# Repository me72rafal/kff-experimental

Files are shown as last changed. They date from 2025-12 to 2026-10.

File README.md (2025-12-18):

# Kung Fu Flash

Cartridge for the Commodore 64 that packs a punch.

Kung Fu Flash Launcher

Kung Fu Flash can emulate different cartridge types, load PRG files and use D64 disk images.
Just place your desired CRT, PRG or D64 files on a FAT formatted microSD card and use the built-in launcher to execute them.

## Hardware

There are three buttons on the cartridge; a reset button, a menu button for starting the launcher, and a special button that is used by the freezer cartridges.

Cartridge Case

The PCB will fit the Stumpy Cartridge Case from TFW8b, you just need to drill some holes for the buttons and make a cut for the microSD card.
If you have mounted the USB connector you will need to cut a hole for that as well.

You can also 3D print a cartridge case as the one designed by bigby, [see here](https://www.thingiverse.com/thing:4153414).

Kung Fu Flash PCB

The gerber files and BOM can be found [here](https://codeberg.org/KimJorgensen/KungFuFlash/releases/tag/rev.2).

## Supported Cartridges

The following cartridge types are currently supported:

* Generic cartridge (8k, 16k, Ultimax)
* Action Replay v4.x/v5/v6
* KCS Power Cartridge
* Final Cartridge III(+)
* Simons' BASIC
* Fun Play, Power Play
* Super Games
* Ocean type 1
* Epyx Fastload
* C64 Game System, System 3
* WarpSpeed
* Dinamic
* Zaxxon, Super Zaxxon
* Magic Desk, Domark, HES Australia
* Super Snapshot v5
* Comal-80
* Ross
* EasyFlash
* Prophet64
* Freeze Frame
* Freeze Machine
* MACH 5
* Pagefox
* RGCD, Hucky
* Drean
* C128 Generic cartridge (external function ROM)
* WarpSpeed 128

## Supported File Types

The following file types are currently supported:

* Cartridge (CRT)
* C64/C128 generic cartridge (ROM, BIN)
* Disk image (D64, D71, D81)
* Tape image (T64)
* Program (PRG, P00)
* Firmware update (UPD)
* Text document (TXT, NFO, 1ST)

## USB Port

The USB port allows programs or disk images to be transferred from/to a PC using the EasyFlash 3 USB protocol.
The USB port is active when:

* The Kung Fu Flash launcher is running
* A program is started using "Load" in the file options menu (SHIFT+RETURN)
* BASIC is started via F7 in the launcher

Kung Fu Flash shows up as a standard serial port when connected to a PC not requiring any custom drivers to be installed.
This means, however, that the EasyFlash 3 program on the PC side must be modified to support Kung Fu Flash.
For that reason a modified version of [EasyFlash 3 USB Utilities](3rd_party/ef3utils) and [EasyFlash 3 BBS](3rd_party/ef3bbs) has been included in this repository.

## Firmware Update

Just place the KungFuFlash_v1.xx.upd file on the SD card and select the file in the launcher to initiate the firmware update.
The newest firmware can be found [here](https://codeberg.org/KimJorgensen/KungFuFlash/releases/).

For initial firmware installation, [see here](firmware/README.md).

## Limitations

Kung Fu Flash is a so called Software Defined Cartridge where a fast microcontroller emulates cartridge hardware in software.
This makes it extremely flexible, allowing different cartridge types to be supported at a relative low cost.

However, it can be challenging to get the C64 bus timing correct in software and in some places the timing is very close to the limit.
Even though Kung Fu Flash has been tested on different models of the Commodore 64, there is a chance that it doesn't work correctly on your specific model, or requires [phi2 offset adjustment](firmware/README.md#diagnostic).
Use it at your own risk!

Kung Fu Flash will work with the PAL and NTSC version of the Commodore 64 or Commodore 128.

Disk drive emulation is using kernal vectors and will not work with fast loaders or software that uses direct hardware access which a lot of games does.
Currently REL files are not supported and only a subset of the Commodore DOS commands are supported.

## Thanks

Kung Fu Flash was based on or uses other open source projects:

* [EasyFlash 3](https://bitbucket.org/skoe/easyflash) by Thomas Giesel
* [Draco Browser](https://csdb.dk/release/?id=89910) by Sascha Bader
* [fatfs-stm32](https://github.com/colosimo/fatfs-stm32) by Aurelio Colosimo
* [FatFs](http://elm-chan.org/fsw/ff/00index_e.html) by ChaN
* [libusb_stm32](https://github.com/dmitrystu/libusb_stm32) by Dmitry Filimonchuk
* [stm32f4-bare-metal](https://github.com/fcayci/stm32f4-bare-metal) by Furkan Cayci
* [OpenC64Cart](https://github.com/SukkoPera/OpenC64Cart) by Giorgioggì
* [EasyFlash 3 USB Utilities](https://csdb.dk/release/?id=150097) by Tomaz Kac
* [Disk2easyflash](https://csdb.dk/release/?id=150323) by ALeX Kazik

and a few others. Please check the individual files for their license.

Thanks to Bjørn N. Jørgensen for giving this project its name.

Special thanks to the author of [Sidekick64](https://github.com/frntc/Sidekick64) Carsten Dachsbacher for his support and inspiration.

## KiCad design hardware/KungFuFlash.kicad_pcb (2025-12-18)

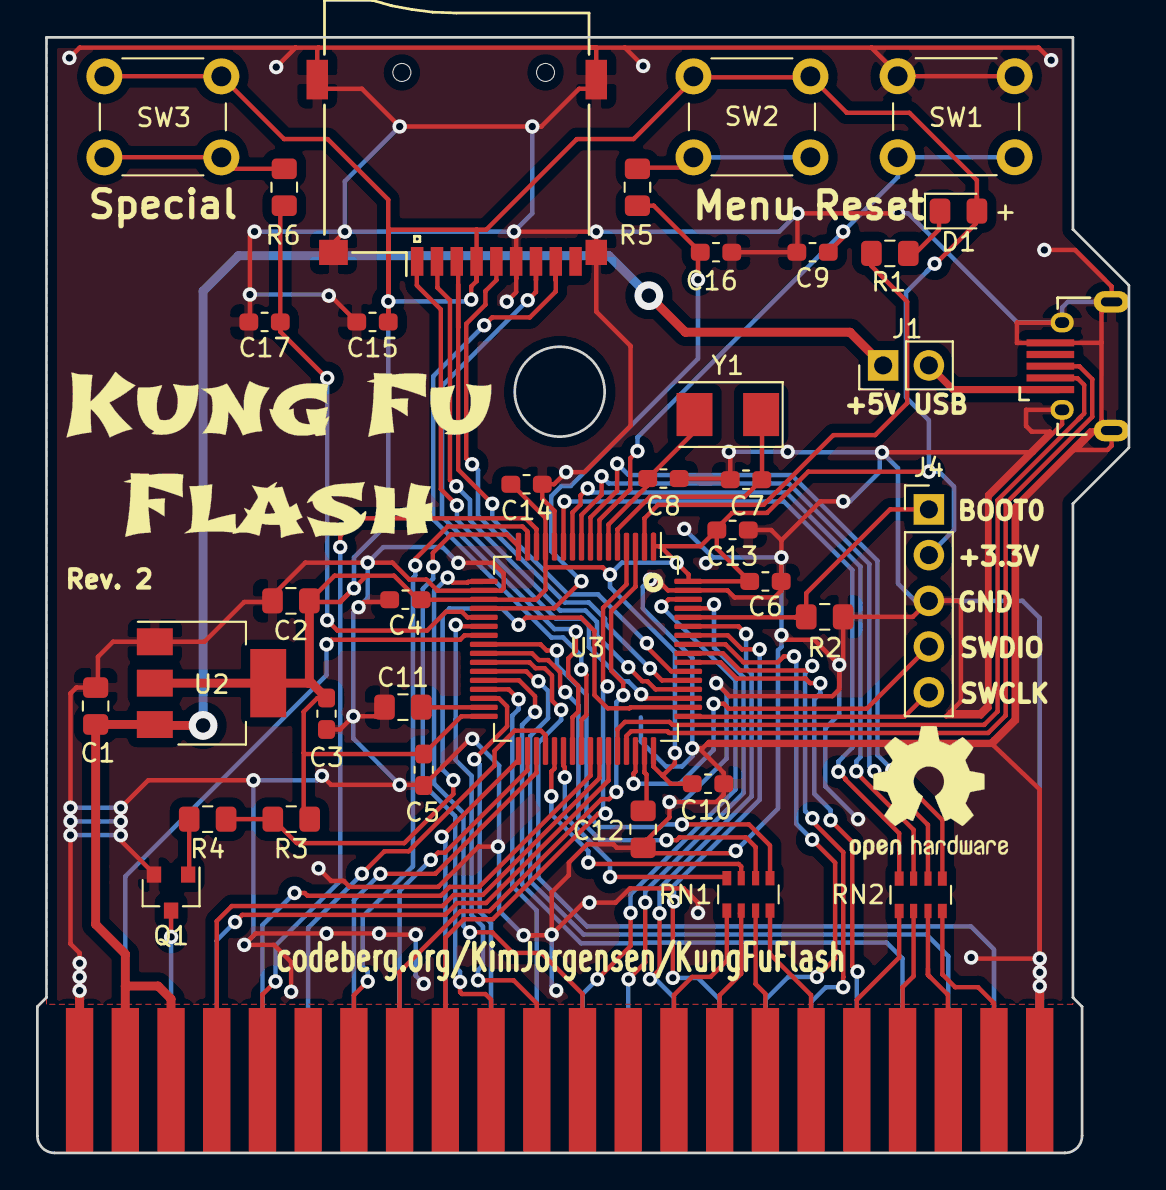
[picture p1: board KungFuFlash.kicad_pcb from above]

Board: 2 copper layers, 60.6 x 62.0 mm, 38 parts (0 on the bottom side), 72 nets.

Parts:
C1, C2: 10u; C_0805_2012Metric_Pad1.15x1.40mm_HandSolder
C3, C4, C5, C6, C9, C10, C13, C14, C15, C16, C17: 100n; C_0603_1608Metric_Pad1.05x0.95mm_HandSolder
C7, C8: 20p; C_0603_1608Metric_Pad1.05x0.95mm_HandSolder
C11, C12: 2.2u; C_0805_2012Metric_Pad1.15x1.40mm_HandSolder
D1: LED; LED_0805_2012Metric_Pad1.15x1.40mm_HandSolder
J1: USB Power; PinHeader_1x02_P2.54mm_Vertical
J2: USB_B_Micro; Conn_USBmicro-B_ebay-side_TH
J4: SWD; PinHeader_1x05_P2.54mm_Vertical
Q1: BC817; SOT-23
R1, R4, R5, R6: 510R; R_0805_2012Metric_Pad1.15x1.40mm_HandSolder
R2, R3: 10k; R_0805_2012Metric_Pad1.15x1.40mm_HandSolder
RN1, RN2: 100R; R_Array_Convex_4x0603
SW1: Reset; SW_PUSH_6mm_H8mm
SW2: Menu; SW_PUSH_6mm_H8mm
SW3: Special; SW_PUSH_6mm_H8mm
U1: C64-Exp-Port; C64-Cart
U2: AMS1117-3.3; SOT-223-3_TabPin2
U3: STM32F405RGTx; LQFP-64_10x10mm_P0.5mm
XS1: uSD_push_push; Conn_uSDcard
Y1: 8MHz; Crystal_SMD_5032-2Pin_5.0x3.2mm

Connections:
+3V3: C2.1, C3.1, C4.1, C5.1, C6.1, C10.1, C13.1, C14.1, C15.1, D1.2, J4.2, R3.1, SW2.1, SW3.1, U2.2, U3.1, U3.13, U3.19, U3.32, U3.48, U3.64, XS1.4
+5C: J1.2, J2.1
+5V: C1.1, J1.1, U1.2, U1.3, U2.3
/A0: U1.Y, U3.26
/A1: U1.X, U3.27
/A2: U1.W, U3.28
/A3: U1.V, U3.55
/A4: U1.U, U3.56
/A5: U1.T, U3.57
/A6: U1.S, U3.58
/A7: U1.R, U3.59
/A8: U1.P, U3.61
/A9: U1.N, U3.62
/A10: U1.M, U3.29
/A11: U1.L, U3.30
/A12: U1.K, U3.33
/A13: U1.J, U3.34
/A14: U1.H, U3.35
/A15: U1.F, U3.36
/BA: U1.12, U3.17
/BOOT0: J4.1, R2.1, U3.60
/CD0: RN2.4, U1.21
/CD1: RN2.3, U1.20
/CD2: RN2.2, U1.19
/CD3: RN2.1, U1.18
/CD4: RN1.4, U1.17
/CD5: RN1.3, U1.16
/CD6: RN1.2, U1.15
/CD7: RN1.1, U1.14
/D0: RN2.5, U3.8
/D1: RN2.6, U3.9
/D2: RN2.7, U3.10
/D3: RN2.8, U3.11
/D4: RN1.5, U3.24
/D5: RN1.6, U3.25
/D6: RN1.7, U3.37
/D7: RN1.8, U3.38
/MENU: C16.1, R5.2, U3.20
/PHI2: U1.E, U3.41
/R~W: U1.5, U3.14
/SD_CK: U3.53, XS1.5
/SD_CMD: U3.54, XS1.3
/SD_D0: U3.39, XS1.7
/SD_D1: U3.40, XS1.8
/SD_D2: U3.51, XS1.1
/SD_D3: U3.52, XS1.2
/SPECIAL: C17.1, R6.2, U3.21
/SWCLK: J4.5, U3.49
/SWDIO: J4.4, U3.46
/USB_DM: J2.2, U3.44
/USB_DP: J2.3, U3.45
/~EXROM: U1.9, U3.4
/~GAME: U1.8, U3.3
/~IO1: U1.7, U3.15
/~IO2: U1.10, U3.16
/~IRQ: U1.4, U3.42
/~LED: R1.1, U3.2
/~NMI: U1.D, U3.43
/~RESET: Q1.3, U1.C
/~ROMH: U1.B, U3.23
/~ROML: U1.11, U3.22
/~RST: C9.1, SW1.2, U3.7
/~RST_O: R3.2, R4.2, U3.50
GND: C1.2, C2.2, C3.2, C4.2, C5.2, C6.2, C7.1, C8.2, C9.2, C10.2, C11.1, C12.2, C13.2, C14.2, C15.2, C16.2, C17.2, J2.5, J2.6, J4.3, Q1.2, R2.2, SW1.1, U1.1, U1.22, U1.A, U1.Z, U2.1, U3.12, U3.18, U3.63, XS1.6
unnamed: C7.2, U3.5, Y1.1
unnamed: C8.1, U3.6, Y1.2
unnamed: C11.2, U3.31
unnamed: C12.1, U3.47
unnamed: D1.1, R1.2
unnamed: Q1.1, R4.1
unnamed: R5.1, SW2.2
unnamed: R6.1, SW3.2

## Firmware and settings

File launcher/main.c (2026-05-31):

/*
 * Copyright (c) 2019-2026 Kim Jørgensen
 *
 * This software is provided 'as-is', without any express or implied
 * warranty.  In no event will the authors be held liable for any damages
 * arising from the use of this software.
 *
 * Permission is granted to anyone to use this software for any purpose,
 * including commercial applications, and to alter it and redistribute it
 * freely, subject to the following restrictions:
 *
 * 1. The origin of this software must not be misrepresented; you must not
 *    claim that you wrote the original software. If you use this software
 *    in a product, an acknowledgment in the product documentation would be
 *    appreciated but is not required.
 * 2. Altered source versions must be plainly marked as such, and must not be
 *    misrepresented as being the original software.
 * 3. This notice may not be removed or altered from any source distribution.
 *
 ******************************************************************************
 * Derived from Draco Browser V1.0C 8 Bit (27.12.2009)
 * Created 2009 by Sascha Bader
 *
 * The code can be used freely as long as you retain
 * a notice describing original source and author.
 *
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
 * Newer versions might be available here: http://www.sascha-bader.de/html/code.html
 */

#include <stdio.h>
#include <string.h>
#include <stdlib.h>
#include <stdbool.h>
#include <ctype.h>
#include <conio.h>
#include <cbm.h>
#include <errno.h>
#include <joystick.h>
#include "screen.h"
#include "dir.h"
#include "base.h"
#include "kff_data.h"
#include "ef3usb_loader.h"
#include "disk.h"
#include "launcher_asm.h"

/* declarations */
static void mainLoopEF3(void);
static void mainLoopKFF(void);
static void textReaderLoop(void);
static uint8_t menuLoop(void);

static void updateScreen(void);
static void help(void);
static bool isSearchChar(uint8_t c);
static uint8_t search(uint8_t c);
static void showDir(void);
static void updateDir(uint8_t last_selected);
static void printDirPage(void);
static void printElement(uint8_t pos);

static const char *kff_receive_text(uint16_t size);
static const char *kff_read_text(void);
static uint8_t kff_sync(void);
static void showFrame(const char *title);
static void showKFFMessage(uint8_t color);
static void showKFFCancel(void);
static void showMessage(const char *text, uint8_t color);

/* definitions */
#define EF3_USB_CMD_LEN 12

static bool isC128 = false;

static char linebuffer[SCREENW+1];
static char inputBuffer[SEARCH_LENGTH+1];
static char searchBuffer[SEARCH_LENGTH+1];
static uint8_t searchLen;
static uint8_t *bigBuffer = NULL;
static uint16_t *pageBuffer = NULL;
static Directory *dir = NULL;

// Use different name to bypass FW update check for NTSC users (prior v1.32)
#define KUNG_FU_FLASH_VER_UPD "Kung Fu Flash " ## KFF_VER " "
#define KUNG_FU_FLASH_VER "Kung Fu Flash v" ## KFF_VER

// Place program name in the start of the output file
// so it can be read by the firmware
#pragma rodata-name (push, "LOWCODE")
const char programNameVer[FW_NAME_SIZE] = KUNG_FU_FLASH_VER_UPD;
#pragma rodata-name (pop)

static const char programBar[] = {"          " KUNG_FU_FLASH_VER "           "};
static const char menuBar[] =    {"          " KUNG_FU_FLASH_VER "  <F1> Help"};

int main(void)
{
    uint8_t i, tmp, tst;
    initScreen(COLOR_BLACK, COLOR_BLACK, TEXTC);

    dir = (Directory *)malloc(sizeof(Directory));
    bigBuffer = (uint8_t *)dir;
    pageBuffer = (uint16_t *)dir;

    if (dir == NULL)
    {
        showMessage("Failed to allocate memory.", ERRORC);
        while (true);
    }

    if (joy_install(&joy_static_stddrv) != JOY_ERR_OK)
    {
        showMessage("Failed to install joystick driver.", ERRORC);
        while (true);
    }

    isC128 = is_c128() != 0;

    if (USB_STATUS == KFF_ID_VALUE) // KFF mode
    {
        mainLoopKFF();
    }
    else    // EF3 mode
    {
        // We can also end up here if there is a hardware problem
        // Test EF3 RAM to make sure we are indeed in EF3 mode
        tst = tmp = EF_RAM_TEST;
        for (i=0; i<=8; i++)
        {
            if (EF_RAM_TEST != tst)
            {
                showMessage("Communication with cartridge failed.", ERRORC);
                cprintf("Check hardware");
                while (true);
            }
            EF_RAM_TEST = tst = 1<<i;
        }
        EF_RAM_TEST = tmp;

        mainLoopEF3();
    }

    free(dir);
    return 0;
}

static void mainLoopEF3(void)
{
    uint8_t i;
    const char *cmd;

    // Get command from Kung Fu Flash cartridge using the EF3 USB protocol
    for (i=0; i<EF3_USB_CMD_LEN; i++)
    {
        cmd = ef3usb_check_cmd();
    }

    while (true)
    {
        if (cmd == NULL)
        {
            showMessage("Communicating with USB...", WARNC);
        }
        else if (strcmp(cmd, "prg") == 0)   // Load PRG
        {
            ef3usb_send_str("load");
            ef3usb_load_and_run();
        }
        else
        {
            showMessage("Received unsupported command.", ERRORC);
            cprintf("Command: %s", cmd);
            ef3usb_send_str("etyp");
        }

        while (!(cmd = ef3usb_check_cmd()));
    }
}

static void mainLoopKFF(void)
{
    const char *text;
    uint8_t cmd, reply, cxy[3];
    uint16_t cmd_wait = 0;

    // Get command from Kung Fu Flash cartridge using the KFF protocol
    while (!(cmd = KFF_GET_COMMAND()) || cmd >= REPLY_OK)
    {
        if (++cmd_wait > 10000)
        {
            cmd_wait = 0;
            showMessage("Waiting for command from cartridge.", ERRORC);
            cprintf("Command: %x", cmd);
        }
    }

    while (true)
    {
        reply = REPLY_OK;
        switch (cmd)
        {
            case CMD_NONE:
                break;

            case CMD_MESSAGE:
                showKFFMessage(TEXTC);
                break;

            case CMD_WARNING:
                showKFFMessage(WARNC);
                waitKey();
                reply = kff_sync();
                break;

            case CMD_FLASH_MESSAGE:
                showKFFMessage(TEXTC);
                textcolor(ERRORC);
                cprintf("PLEASE DO NOT POWER OFF OR RESET");
                reply = kff_sync();
                break;

            case CMD_CANCEL_MESSAGE:
                showKFFCancel();
                reply = kff_sync();
                break;

            case CMD_TEXT:
            case CMD_TEXT_WAIT:
                kff_receive_data(&cxy, sizeof(cxy));
                text = kff_read_text();
                textcolor(cxy[0]);
                cputsxy(cxy[1], cxy[2], text);
                if (cmd == CMD_TEXT_WAIT)
                {
                    reply = kff_sync();
                }
                break;

            case CMD_TEXT_READER:
                textReaderLoop();
                wait_for_reset();
                break;

            case CMD_MENU:
                cmd = menuLoop();
                continue;

            case CMD_WAIT_SYNC:
                clrscr();
                reply = kff_sync();
                break;

            case CMD_MOUNT_DISK:
                disk_mount_and_load();
                break;

            case CMD_WAIT_RESET:
                wait_for_reset();
                break;

            default:
                showMessage("Communication with cartridge failed.", ERRORC);
                cprintf("Unexpected command: %x", cmd);
                break;
        }

        cmd = kff_send_reply(reply);
    }
}

static const char *kff_receive_text(uint16_t size)
{
    kff_receive_data(bigBuffer, size);
    bigBuffer[size] = 0;

    return bigBuffer;
}

static const char *kff_read_text(void)
{
    uint16_t size;
    kff_receive_data(&size, 2);

    return kff_receive_text(size);
}

static void showKFFMessage(uint8_t color)
{
    const char *text = kff_read_text();
    showMessage(text, color);
}

static void showKFFCancel(void)
{
    const char *text = kff_receive_text(DIR_NAME_LENGTH);
    sprintf(linebuffer, " >%-36s< ", text);
    showFrame(linebuffer);

    textcolor(TEXTC);
    text = kff_read_text();
    cputsxy(0, 3, text);

    textcolor(ERRORC);
    cputsxy(0, 5, "PLEASE DO NOT POWER OFF OR RESET");

    revers(1);
    textcolor(COLOR_PURPLE);
    cputsxy(0, 11, "PRESS A KEY TO CANCEL");
    revers(0);
}

static uint8_t kff_sync(void)
{
    kff_wait_for_sync();

    if (kbhit() || joyhit())
    {
        return REPLY_CANCEL;
    }

    return REPLY_OK;
}

static void showTextPage(uint16_t page)
{
    uint8_t i, chr, last_c = 0;

    clrscr();
    revers(1);
    textcolor(BACKC);
    cputsxy(0, 0, " >");
    KFF_READ_PTR = 0;
    for (i=0; i<DIR_NAME_LENGTH; i++)
    {
        cputc(KFF_DATA);
    }
    cputs("< ");
    cputsxy(0, BOTTOM, programBar);
    revers(0);
    textcolor(TEXTC);
    gotoxy(0, 1);

    KFF_READ_PTR = pageBuffer[page];
    while (true)
    {
        chr = KFF_DATA;
        if (!chr || wherey() >= 24)
        {
            (KFF_READ_PTR)--;
            break;
        }

        if (chr == 0x0a && last_c != 0x0d)  // Handle line endings
        {
            cputs("\r\n");
        }
        else if (chr == 0x09)   // Handle tab
        {
            if ((wherex() % 2) == 0)
            {
                cputs("  ");
            }
            else
            {
                cputc(' ');
            }
        }
        else
        {
            cputc(chr);
        }

        last_c = chr;
    }

    pageBuffer[page + 1] = KFF_READ_PTR;
}

static void textReaderLoop(void)
{
    uint8_t c;
    uint16_t size, page = 0;

    KFF_READ_PTR = DIR_NAME_LENGTH;
    kff_receive_data(&size, 2);
    size++;
    pageBuffer[0] = KFF_READ_PTR;
    showTextPage(0);

    waitRelease();
    while (true)
    {
        c = kbhit() ? cgetc() : getJoy();
        switch (c)
        {
            case CH_ENTER:
            case CH_SHIFT_ENTER:
            case CH_DEL:
            case CH_STOP:
                return;

            case CH_HOME:
            case CH_FIRE_LEFT:
            case CH_FIRE_UP:
                page = 0;
                showTextPage(page);
                break;

            case CH_CURS_DOWN:
            case CH_CURS_RIGHT:
                if (KFF_READ_PTR < size && page < (sizeof(Directory)/2))
                {
                    showTextPage(++page);
                }
                break;

            case CH_CURS_LEFT:
            case CH_CURS_UP:
                if (page)
                {
                    showTextPage(--page);
                }
                break;

            default:
                break;
        }
    }
}

static void updateScreen(void)
{
    clrscr();
    revers(0);
    textcolor(BACKC);
    drawFrame();
    revers(1);
    cputsxy(0, BOTTOM, menuBar);
    revers(0);

    showDir();
}

static uint8_t menuLoop(void)
{
    uint8_t c, last_selected = 0;
    uint8_t data, cmd, reply;

    memset(dir, 0, sizeof(Directory));
    updateScreen();

    cmd = CMD_NONE;
    kff_send_size_data(searchBuffer, searchLen);
    reply = REPLY_DIR;

    while (true)
    {
        if (cmd != CMD_NONE || reply != REPLY_OK)
        {
            cmd = kff_send_reply_progress(reply);
        }

        reply = REPLY_OK;
        switch (cmd)
        {
            case CMD_NONE:
                break;

            case CMD_READ_DIR:
                readDir(dir);
                showDir();
                waitRelease();
                continue;

            case CMD_READ_DIR_PAGE:
                if (!readDirPage(dir))
                {
                    dir->selected = last_selected;
                }

                if (dir->selected >= dir->no_of_elements)
                {
                    dir->selected =
                        dir->no_of_elements ? dir->no_of_elements-1 : 0;
                }

                if (dir->selected < dir->text_elements)
                {
                    dir->selected = dir->text_elements;
                }

                showDir();
                continue;

            default:
                return cmd;
        }

        c = kbhit() ? cgetc() : getJoy();
        switch (c)
        {
            case CH_NONE:
                break;

            // --- start / enter directory
            case CH_ENTER:
            case CH_SHIFT_ENTER:
                if (dir->no_of_elements)
                {
                    data = dir->selected;
                    if (isC128)
                    {
                        data |= SELECT_FLAG_C128;
                    }
                    if (c == CH_SHIFT_ENTER)
                    {
                        data |= SELECT_FLAG_OPTIONS;
                    }

                    KFF_SEND_BYTE(data);
                    reply = REPLY_SELECT;
                }
                break;

            // --- leave directory
            case CH_DEL:
            case CH_FIRE_LEFT:
                if (searchBuffer[0] && *dir->name != ' ')
                {
                    reply = search(c);
                }
                else
                {
                    reply = REPLY_DIR_UP;
                }
                break;

            // --- root directory
            case CH_HOME:
                if (searchBuffer[0] && *dir->name != ' ')
                {
                    reply = search(c);
                }
                else
                {
                    reply = REPLY_DIR_ROOT;
                }
                break;

            case CH_CURS_DOWN:
                if (dir->no_of_elements)
                {
                    last_selected = dir->selected;
                    if ((dir->selected+1) < dir->no_of_elements)
                    {
                        dir->selected++;
                        updateDir(last_selected);
                    }
                    else if (dir->no_of_elements == MAX_ELEMENTS_PAGE)
                    {
                        dir->selected = 0;
                        reply = REPLY_DIR_NEXT_PAGE;
                    }
                }
                break;

            case CH_CURS_UP:
                if (dir->no_of_elements)
                {
                    last_selected = dir->selected;
                    if (dir->selected > dir->text_elements)
                    {
                        dir->selected--;
                        updateDir(last_selected);
                    }
                    else
                    {
                        dir->selected = MAX_ELEMENTS_PAGE-1;
                        reply = REPLY_DIR_PREV_PAGE;
                    }
                }
                break;

            case CH_CURS_RIGHT:
                if (dir->no_of_elements)
                {
                    if (dir->no_of_elements < MAX_ELEMENTS_PAGE)
                    {
                        last_selected = dir->selected;
                        dir->selected = dir->no_of_elements-1;
                        updateDir(last_selected);
                    }
                    else
                    {
                        last_selected = dir->no_of_elements-1;
                        reply = REPLY_DIR_NEXT_PAGE;
                    }
                }
                break;

            case CH_CURS_LEFT:
                if (dir->no_of_elements)
                {
                    last_selected = 0;
                    reply = REPLY_DIR_PREV_PAGE;
                }
                break;

            // --- search
            case CH_INS:
            case CH_FIRE_UP:
                if (*dir->name != ' ')
                {
                    reply = search(c);
                }
                break;

            // --- clear search
            case CH_CLR:
                if (searchBuffer[0] && *dir->name != ' ')
                {
                    reply = search(c);
                }
                break;

            case CH_F1:
                help();
                break;

            case CH_F3:
                reply = REPLY_UTILITIES;
                break;

            case CH_FIRE_DOWN:
                if (searchBuffer[0] && *dir->name != ' ')
                {
                    reply = search(c);
                }
                else
                {
                    reply = REPLY_UTILITIES;
                }
                break;

            case CH_F5:
                reply = REPLY_SETTINGS;
                break;

            case CH_FIRE_RIGHT:
                if (searchBuffer[0] && *dir->name != ' ')
                {
                    reply = search(c);
                }
                else
                {
                    reply = REPLY_SETTINGS;
                }
                break;

            case CH_F6:
                reply = REPLY_KILL_C128;
                break;

            case CH_F7:
                reply = REPLY_BASIC;
                break;

            case CH_F8:
                reply = REPLY_KILL;
                break;

            case CH_STOP:
                reply = REPLY_RESET;
                break;

            default:
                if (isSearchChar(c) && *dir->name != ' ')
                {
                    reply = search(c);
                }
                break;
        }
    }
}

static bool isSearchChar(uint8_t c)
{
    return (c >= 0x20 && c <= 0x5f) || (c >= 0xc1 && c <= 0xda);
}

static uint8_t search(uint8_t c)
{
    uint8_t cursor_pos, cursor_delay;
    bool changed = false;
    uint8_t i, last_selected = dir->selected;

    dir->selected++;
    printElement(last_selected);
    dir->selected = last_selected;

    textcolor(TEXTC);
    revers(1);
    memcpy(inputBuffer, searchBuffer, searchLen);

    for (i=searchLen; i<SEARCH_LENGTH; i++)
    {
        inputBuffer[i] = ' ';
    }
    inputBuffer[SEARCH_LENGTH] = 0;

    cursor_pos = searchLen < SEARCH_LENGTH ? searchLen : SEARCH_LENGTH;

    while (c != CH_ENTER)
    {
        if (c == CH_HOME)
        {
            cursor_pos = 0;
        }
        else if (c == CH_DEL || c == CH_FIRE_LEFT)
        {
            if (cursor_pos)
            {
                cursor_pos--;
            }
            else
            {
                break;
            }

            for (i=cursor_pos; i<SEARCH_LENGTH-1; i++)
            {
                inputBuffer[i] = inputBuffer[i+1];
            }
            inputBuffer[SEARCH_LENGTH-1] = ' ';
        }
        else if (c == CH_CURS_LEFT)
        {
            if (cursor_pos)
            {
                cursor_pos--;
            }
        }
        else if (c == CH_CLR || c == CH_FIRE_DOWN)
        {
            memset(inputBuffer, ' ', SEARCH_LENGTH);
            break;
        }
        else if (cursor_pos < SEARCH_LENGTH)
        {
            if (c == CH_INS || c == CH_FIRE_UP)
            {
                for (i=SEARCH_LENGTH-1; i>cursor_pos; i--)
                {
                    inputBuffer[i] = inputBuffer[i-1];
                }
                inputBuffer[cursor_pos] = ' ';
            }
            else if (c == CH_CURS_RIGHT)
            {
                cursor_pos++;
            }
            else if (c == CH_CURS_UP)
            {
                c = inputBuffer[cursor_pos] + 1;
                if (c < 0x2a)   // '*'
                {
                    c = 'a';
                }
                else if (c < 0x30)  // '0'
                {
                    c = '0';
                }
                else if (c > 0x39 && c < 0x41)  // '9' - 'a'
                {
                    c = ' ';
                }
                else if (c > 0x5a)  // 'z'
                {
                    c = '*';
                }

                inputBuffer[cursor_pos] = c;
            }
            else if (c == CH_CURS_DOWN)
            {
                c = inputBuffer[cursor_pos] - 1;
                if (c < 0x20)   // ' '
                {
                    c = '9';
                }
                else if (c < 0x2a)  // '*'
                {
                    c = 'z';
                }
                else if (c < 0x30)   // '0'
                {
                    c = '*';
                }
                else if (c > 0x39 && c < 0x41)  // '9' - 'a'
                {
                    c = ' ';
                }
                else if (c > 0x5a)  // 'z'
                {
                    c = ' ';
                }

                inputBuffer[cursor_pos] = c;
            }
            else if (isSearchChar(c))
            {
                inputBuffer[cursor_pos++] = c;
            }
        }

        sprintf(linebuffer, "> Search: %s <", inputBuffer);
        cputsxy(1, 0, linebuffer);

        cursor_delay = 0;
        while (true)
        {
            if (cursor_delay == 0)
            {
                SCREEN_RAM[11 + cursor_pos] ^= 0x80;
                cursor_delay = 120;
            }
            cursor_delay--;

            if (kbhit())
            {
                c = cgetc();
                if (c != CH_CURS_UP && c != CH_CURS_DOWN)
                {
                    break;
                }
            }

            c = getJoy();
            if (c)
            {
                if (c == CH_FIRE_RIGHT)
                {
                    c = ' ';
                }
                break;
            }
        }
        revers(1);
    }

    for (i=SEARCH_LENGTH; i>0; i--) // remove trailing space
    {
        if (inputBuffer[i-1] == ' ')
        {
            inputBuffer[i-1] = 0;
        }
        else
        {
            break;
        }
    }
    searchLen = i;

    for (i=0; i<=searchLen; i++)
    {
        if (searchBuffer[i] != inputBuffer[i])
        {
            changed = true;
            searchBuffer[i] = inputBuffer[i];
        }
    }

    if (!changed)
    {
        showDir();
        waitRelease();
        return REPLY_OK;
    }

    kff_send_size_data(searchBuffer, searchLen);
    return REPLY_DIR;
}
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

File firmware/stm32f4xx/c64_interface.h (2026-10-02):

/*
 * Copyright (c) 2019-2026 Kim Jørgensen
 *
 * This software is provided 'as-is', without any express or implied
 * warranty.  In no event will the authors be held liable for any damages
 * arising from the use of this software.
 *
 * Permission is granted to anyone to use this software for any purpose,
 * including commercial applications, and to alter it and redistribute it
 * freely, subject to the following restrictions:
 *
 * 1. The origin of this software must not be misrepresented; you must not
 *    claim that you wrote the original software. If you use this software
 *    in a product, an acknowledgment in the product documentation would be
 *    appreciated but is not required.
 * 2. Altered source versions must be plainly marked as such, and must not be
 *    misrepresented as being the original software.
 * 3. This notice may not be removed or altered from any source distribution.
 */

/*************************************************
* C64 address bus on PB0-PB15
* Returned as 32 bit value for performance
*************************************************/
#define C64_ADDR_READ() (GPIOB->IDR)

/*************************************************
* C64 data bus on PC0-PC7
* Returned as 32 bit value for performance
*************************************************/
#define C64_DATA_READ() (GPIOC->IDR)

#define C64_DATA_WRITE(data)                    \
    /* Make PC0-PC7 outout */                   \
    *((volatile u16 *)&GPIOC->MODER) = 0x5555;  \
    *((volatile u8 *)&GPIOC->ODR) = (data);     \
    COMPILER_BARRIER()

#define C64_DATA_INPUT()                        \
    /* Make PC0-PC7 input */                    \
    *((volatile u16 *)&GPIOC->MODER) = 0x0000;  \
    COMPILER_BARRIER()

/*************************************************
* C64 control bus on PA0-PA3 and PA6-PA7
* Menu button & special button on PA4 & PA5
* Returned as 32 bit value for performance
*************************************************/
#define C64_WRITE   0x0001  // R/W on PA0
#define C64_IO1     0x0002  // IO1 on PA1
#define C64_IO2     0x0004  // IO1 on PA2
#define C64_BA      0x0008  // BA on PA3
#define MENU_BTN    0x0010  // Menu button on PA4
#define SPECIAL_BTN 0x0020  // Special button on PA5
#define C64_ROML    0x0040  // ROML on PA6
#define C64_ROMH    0x0080  // ROMH on PA7

#define C64_CONTROL_READ() (GPIOA->IDR)

/*************************************************
* C64 IRQ and NMI on PA9 & PA10
*************************************************/
#define C64_IRQ     0x0200  // IRQ on PA9
#define C64_NMI     0x0400  // NMI on PA10

#define C64_IRQ_HIGH        GPIO_BSRR_BS9
#define C64_IRQ_LOW         GPIO_BSRR_BR9
#define C64_NMI_HIGH        GPIO_BSRR_BS10
#define C64_NMI_LOW         GPIO_BSRR_BR10
#define C64_IRQ_NMI_HIGH    (C64_IRQ_HIGH|C64_NMI_HIGH)
#define C64_IRQ_NMI_LOW     (C64_IRQ_LOW|C64_NMI_LOW)

#define C64_IRQ_NMI(state) GPIOA->BSRR = (state)

/*************************************************
* C64 GAME and EXROM on PC14 & PC15
* Status LED on PC13
*************************************************/
#define C64_GAME_HIGH   GPIO_BSRR_BS14
#define C64_GAME_LOW    GPIO_BSRR_BR14
#define C64_EXROM_HIGH  GPIO_BSRR_BS15
#define C64_EXROM_LOW   GPIO_BSRR_BR15

#define STATUS_LED_ON   GPIO_BSRR_BR13
#define STATUS_LED_OFF  GPIO_BSRR_BS13

#define C64_CRT_CONTROL(state) GPIOC->BSRR = (state)

static inline void led_off(void)
{
    C64_CRT_CONTROL(STATUS_LED_OFF);
}

static inline void led_on(void)
{
    C64_CRT_CONTROL(STATUS_LED_ON);
}

static inline void led_toggle(void)
{
    GPIOC->ODR ^= GPIO_ODR_OD13;
}

/*************************************************
* C64 clock input on PA8 (timer 1)
*************************************************/

FORCE_INLINE void wait_n_cycles(u32 n_cycles)
{
    asm volatile("1:\n\t"
                 "adds %0, %0, #3\n\t"
                 "ble 1b"
                 :: "r"(n_cycles): "%0", "cc");
}

#define WAIT_CYCLES(cnt, until)                             \
    /* Make cycles to wait negative to reduce code size */  \
    wait_n_cycles(cnt - until)

// C64_BUS_HANDLER timing
#define NTSC_PHI2_HIGH      98
#define NTSC_PHI2_INT       (NTSC_PHI2_HIGH - 42)
#define NTSC_PHI2_LOW       147

#define PAL_PHI2_HIGH       102
#define PAL_PHI2_INT        (PAL_PHI2_HIGH - 43)
#define PAL_PHI2_LOW        153

#define WAIT_UNTIL(until)   \
    while (DWT->CYCCNT < until)


#define C64_BUS_HANDLER(name)                                                   \
    C64_BUS_HANDLER_(name##_handler, name##_read_handler, name##_write_handler)

#define C64_BUS_HANDLER_READ(name, read_handler)                                \
    C64_BUS_HANDLER_(name##_handler, read_handler, name##_write_handler)
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

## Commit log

2025-12-18 Move to Codeberg
    [KungFuFlash.kicad_pcb]
2026-04-06 Add reset to menu via USB
    [usb.c]
2026-10-02 kernal port - not working yet
    [c64_interface.h, hal.c, kernal.c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]
